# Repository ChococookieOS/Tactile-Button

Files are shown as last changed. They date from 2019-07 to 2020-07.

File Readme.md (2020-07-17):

# Smartbutton Rapid Manufacturing

# Problemstellung
Die Erstellung eines haltbaren und universell einsetzbaren Tasters, der leicht reproduziert werden kann und damit zugänglich für zukünftige Smart Technology Projekte ist.
Anforderungen an den Taster:
- stabil
- günstig
- ausrichtungsunabhänig für z.B. Wandmontage
- universell zu integrieren

## Erste Generation
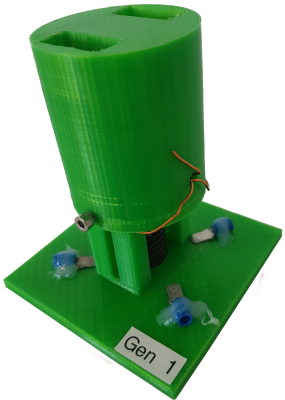
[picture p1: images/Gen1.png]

#### Probleme:
- Federdicke verhindert Kontakt
- Volumen in relation zu Funktionalität viel zu groß
- Unangenehm zu drücken
- Bodenkontakte sehr ungleichmäßig
## Zweite Generation
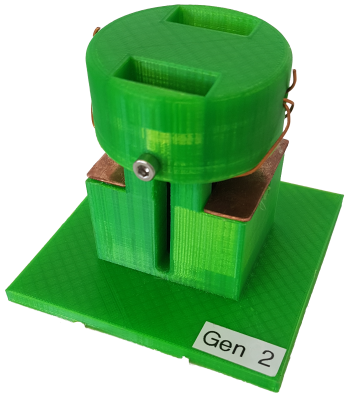
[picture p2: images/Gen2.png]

#### Verbesserungen:
- Bodenkontakte sind Kupferplatten und bieten eine größere Berührungsfläche
- Tasterkopf mit Fase verbessert Druckgefühl

#### Probleme:
- Kontaktführung außerhalb der Langlöcherschienen führen zu inkonsitentem Druckverhalten
- Federstärke erfordert viel zu viel Kraft zum Auslösen des Tasters
- Hohe Toleranzen führen zu diversen Verkantungsmöglichkeiten

## Dritte Generation
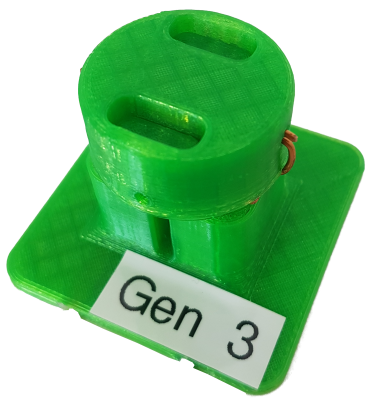
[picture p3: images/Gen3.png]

#### Verbesserungen:
- Volumen auf ein Viertel reduziert
- Kontaktführung auf einen Kupferdraht reduziert um Fertigung und Funktionalität zu vereinfachen
#### Probleme:
- Schienenöffnungen auf der Oberseite stören Druckgefühl
- Podest der Kupferbleche ist zu hoch und damit ist der Druckweg < 1mm

## Vierte  Generation
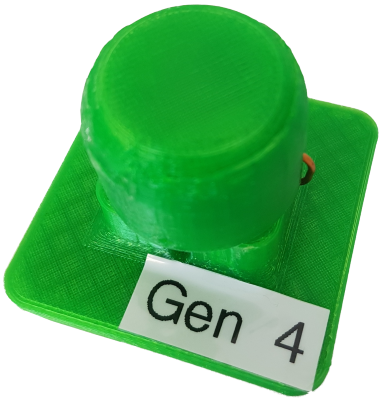
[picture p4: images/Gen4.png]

#### Verbesserungen:
- Herabgesengtes Podest
- Druckfläche geschlossen und ohne störende Kanten
#### Probleme:
- Federn existieren nicht in beliebigen Dimensionen, weswegen keine Feder in das Modell passt
- Druckweg wurde verschoben ist aber immer noch zu kurz

## Fünfte Generation
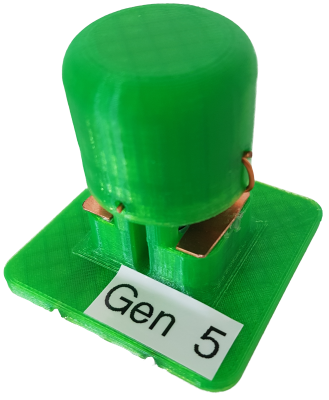
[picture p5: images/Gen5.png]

#### Verbesserungen:

 - Schmalere Vertiefungen
 - Breitere Führungen
 - Längere Langlöcher

#### Probleme:

 - Stromleitungen liegen offen
 - Absichtliches Verkanten möglich

## Sechste Finale Generation 
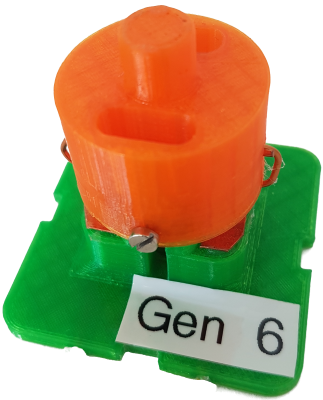
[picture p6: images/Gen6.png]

#### Verbesserungen:

 - Schutz vor Elektrizität durch Schutzhaube
 - Universellerer Formfaktor
 - Kleinerer Druckpunkt verhindert verkanten

### Promo video:
 Promotional video (https://www.youtube.com/watch?v=Kt1wF7Cg-Yw)

# Funktionalität
Durch das herunterdrücken des Tasters wird ein Kupferdraht auf zwei Kupferbleche gedrückt wodurch ein elektrischer Kontakt entsteht.
**Der Button ist selbstsperrend und besitzt keinen eingebauten Widerstand**
# CAD Dateien
Die vollständigen und fertigen *.stl Dateien können im korrespondierenen Verzeichnis [stl](https://github.com/ChococookieOS/Tactile-Button/master/stl) heruntergeladen werden.
# Beispiel Schaltplan
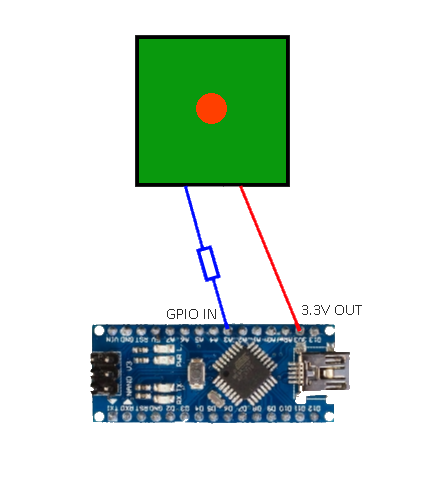
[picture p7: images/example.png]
Verwendung des Buttons als Input

# Komponenten
 - PLA Filament (ca. 40g)
 - Kupferblech (ca. 2cm² x 0.5mm)
 - Kupferdrah (min 4cm)
 - Kabellitze (min 7cm)
 - [Druckfeder](https://www.federnshop.com/de/produkte/druckfedern/d-042f-10.html)(7mm x 20.5mm)

# Produktionskosten
### Kostenaufstellung beim Einzelkauf

| Art | Menge | Preis pro Einheit|
|-----|---|---|
|Filament| 40g| 0,74€|
|Feder | 1 | 2,58€|
|Kupferblech| 2 cm²| 0,0050€|
|Kupferdraht| 6 cm| 0,06€|
|Kabel| 20 cm| 0,04€|
**Summe: 3,43€**

### Kostenaufstellung für 125 Stück:

| Art | Menge | Preis pro Einheit|
|-----|---|---|
|Filament| 40g| 0,74€|
|Feder | 1 | 0,15€|
|Kupferblech| 2 cm²| 0,001€|
|Kupferdraht| 6 cm| 0,02€|
|Kabel| 20 cm| 0,012€|
**Kosten pro Stück: 0,93€**

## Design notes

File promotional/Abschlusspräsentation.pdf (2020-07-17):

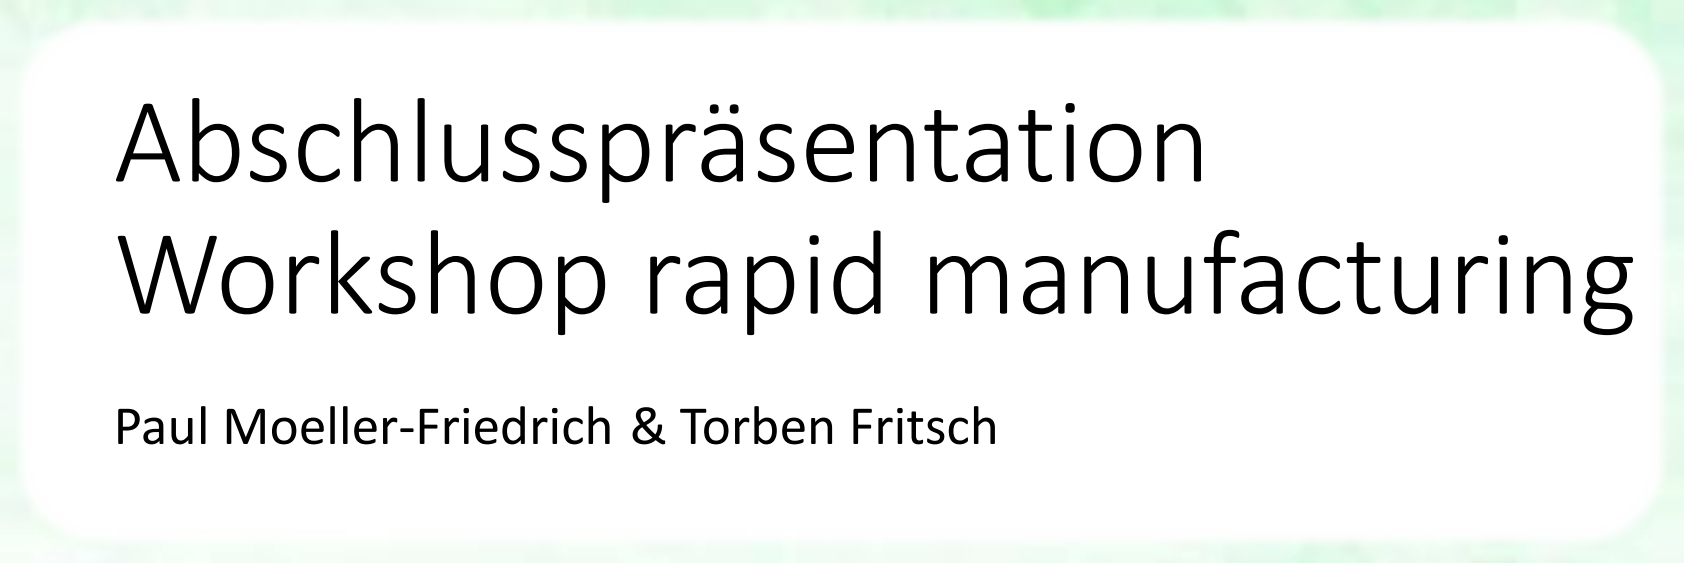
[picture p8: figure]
Abschlusspräsentation Workshop rapid manufacturing; Paul Moeller-Friedrich & Torben Fritsch

# Was bisher geschah:

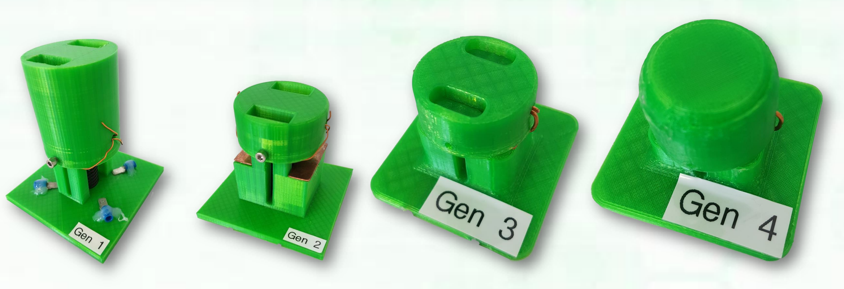
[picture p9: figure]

# Was war zu verbessern:

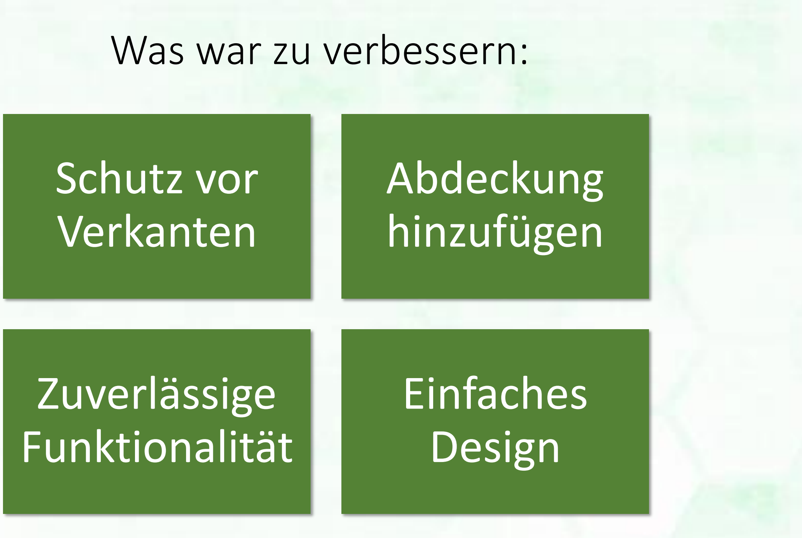
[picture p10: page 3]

# Schutz vor Verkanten

# Abdeckung hinzufügen

# Zuverlässige Funktionalität

# Einfaches Design

# Schutz vor Verkanten / Zuverlässige Funktionalität

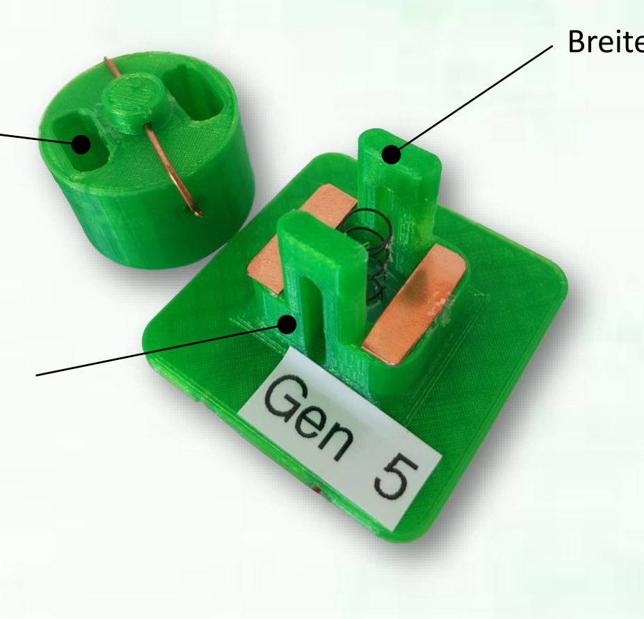
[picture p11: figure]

Breitere Führungen

Längere Langlöcher

Schmalere Vertiefungen

# Abdeckung zum Schutz / Einfaches Design

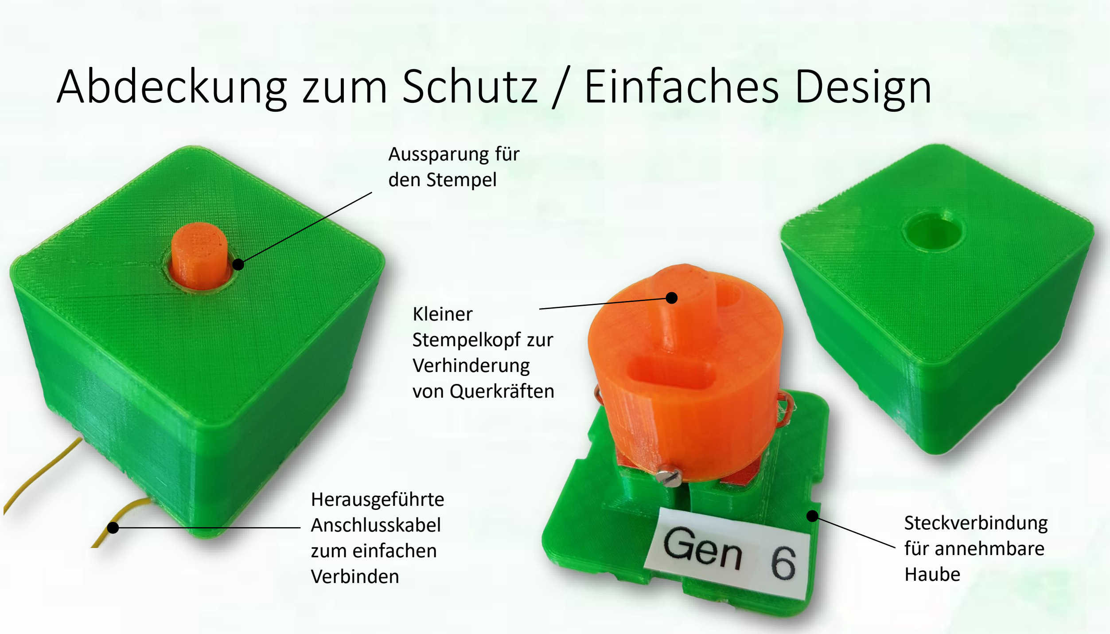
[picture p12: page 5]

Herausgeführte
Anschlusskabel
zum einfachen
Verbinden

Aussparung für
den Stempel

Kleiner
Stempelkopf zur
Verhinderung
von Querkräften

Steckverbindung
für annehmbare
Haube

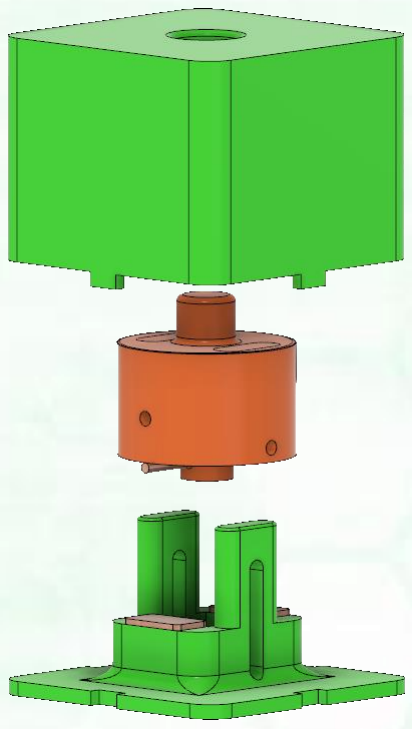
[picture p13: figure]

# Das finale Produkt:

## - Einfach

## - Zuverlässig

## - Sicher

## - Günstig

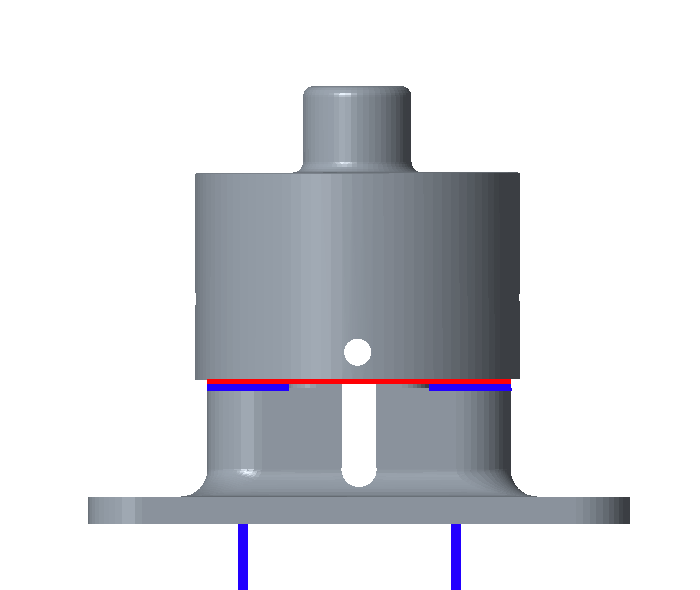
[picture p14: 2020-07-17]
promotional/creo button pressed.png

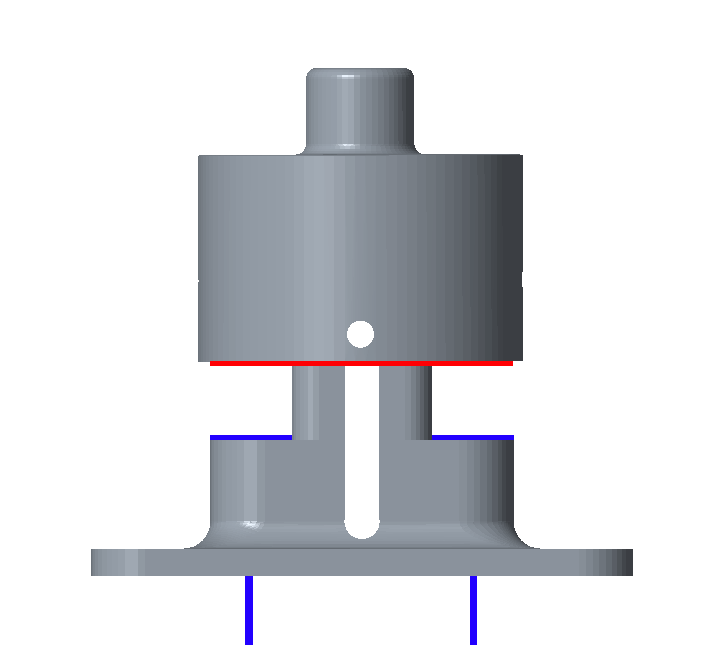
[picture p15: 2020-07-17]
promotional/creo button not pressed.png

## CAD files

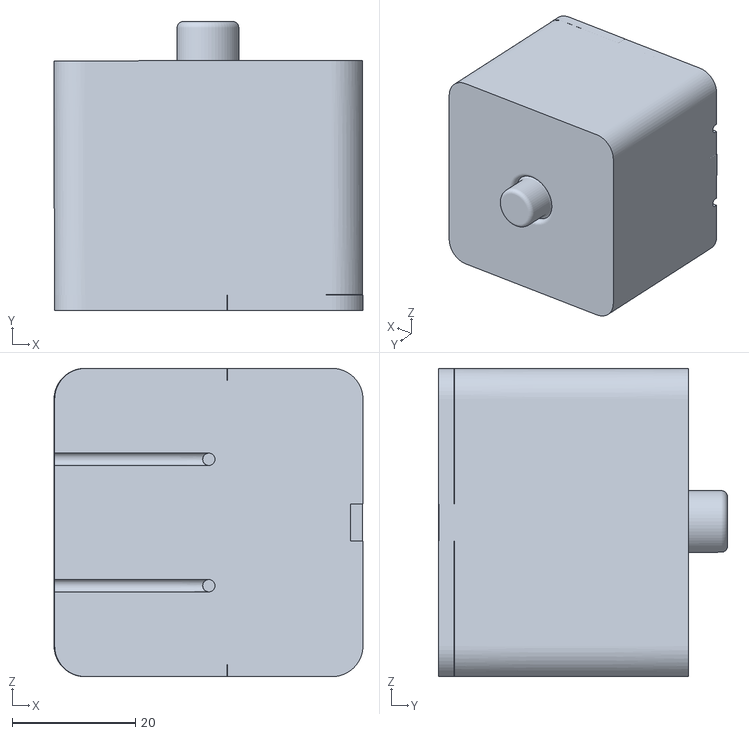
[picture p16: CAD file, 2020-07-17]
stl/button_full.stl
50.1 x 46.9 x 50.0

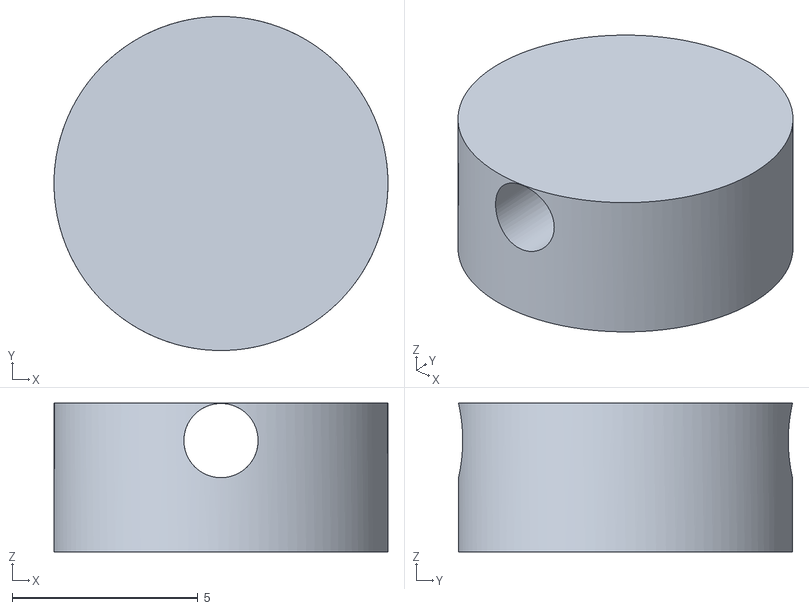
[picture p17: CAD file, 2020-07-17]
stl/Nupsi v8.stl
9.00 x 9.00 x 4.01

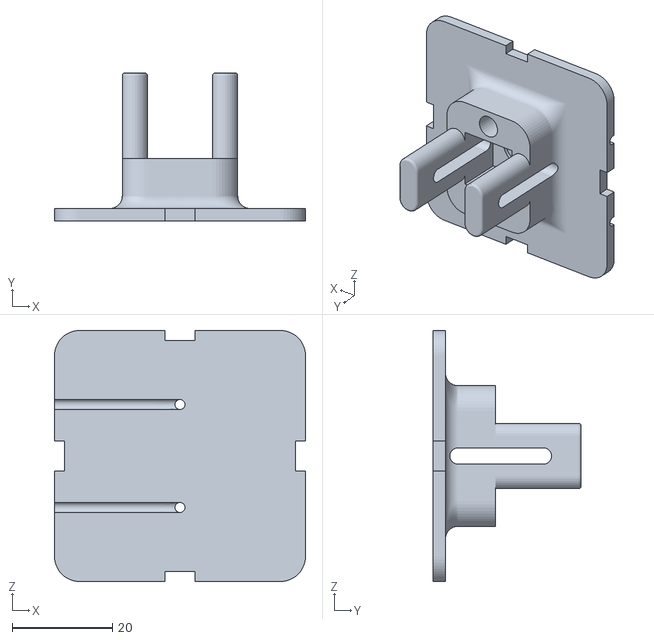
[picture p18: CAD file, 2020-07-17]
stl/Bodenplatte v8.stl
50.0 x 29.5 x 50.0

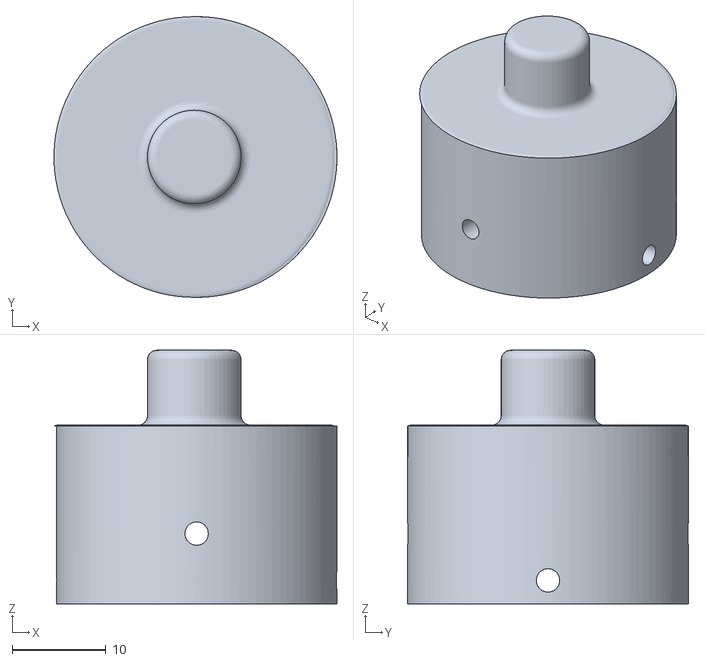
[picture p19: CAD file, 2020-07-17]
stl/Stempel v9.stl
30.2 x 30.0 x 27.1

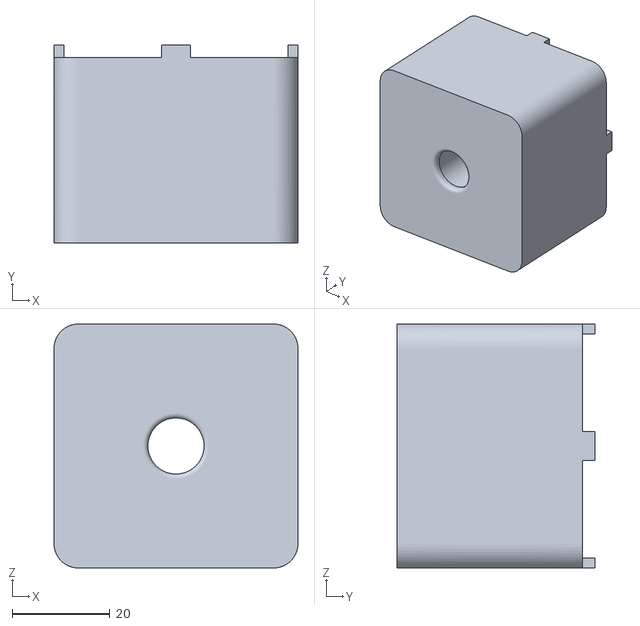
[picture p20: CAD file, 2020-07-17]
stl/Haube v10.stl
50.0 x 40.5 x 50.0

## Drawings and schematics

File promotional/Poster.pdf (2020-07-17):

## Workshop Rapid Manufacturing

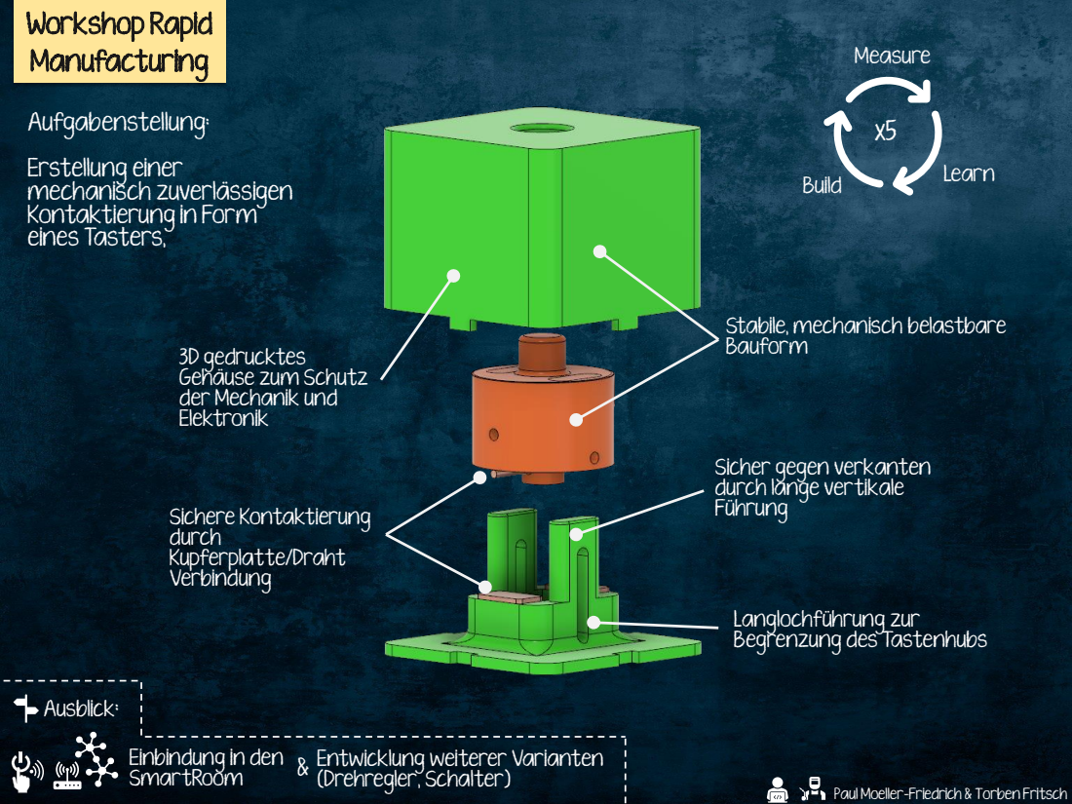
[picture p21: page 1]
Build; Measure; Learn; Ausblick:; SmartRoom; Sichere Kontaktierung durch Kupferplatte/Draht Verbindung

Aufgabenstellung:
Erstellung einer
mechanisch zuverlässigen
Kontaktierung in Form
eines Tasters,

Stabile, mechanisch belastbare
Bauform

3D gedrucktes
Gehäuse zum Schutz
der Mechanik und
Elektronik

Sicher gegen verkanten
durch lange vertikale
Führung

Langlochführung zur
Begrenzung des Tastenhubs

Einbindung in den

Entwicklung weiterer Varianten
(Drehregler, Schalter)

Paul Moeller-Friedrich & Torben Fritsch

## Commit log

2020-07-17 Added stl files
    [Bodenplatte v8.stl, Haube v10.stl, Nupsi v8.stl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]
2020-07-17 Added promo material
